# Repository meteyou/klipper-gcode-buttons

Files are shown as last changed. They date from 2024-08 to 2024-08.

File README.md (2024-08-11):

# Klipper Gcode-Buttons

The Klipper Gcode-Buttons offer a unique control and status display solution in 3D printers and automated systems.
Executing gcodes directly via hardware buttons and displaying the status visually significantly increases
user-friendliness. The CANBUS support as a USB-to-CAN adapter and the additional interfaces, such as SPI and I2C, offer
extra benefits and significantly expand the application possibilities.

To learn more about the Klipper Gcode-Buttons, check out the documentation:
[Klipper Gcode-Buttons Documentation](https://gcode-buttons.meteyou.wtf)

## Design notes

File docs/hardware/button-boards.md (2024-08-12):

# Button Boards

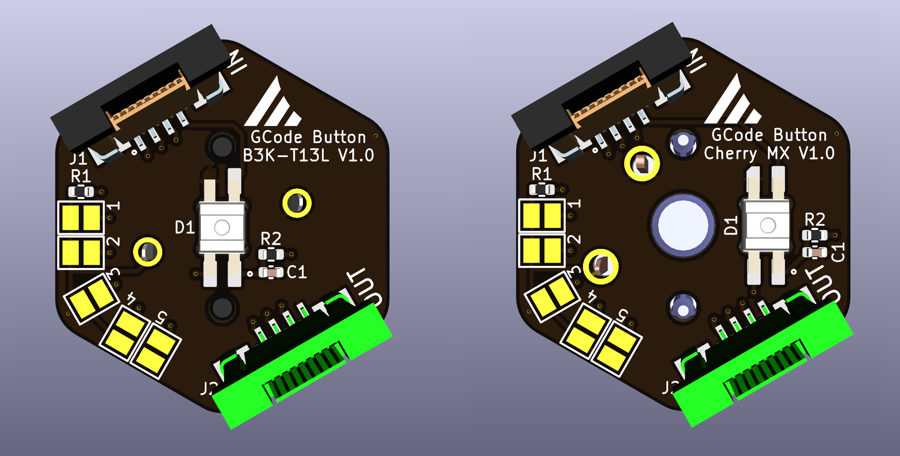
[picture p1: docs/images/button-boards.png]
Button Boards Rendering


The Button Boards are specially developed PCBs that enable intuitive and visually appealing control for Klipper-based 3D
printers. These small PCBs have two versions: one for **Cherry-MX** buttons and one for **Romer-G (B3K-T1RL)** buttons.
Both versions offer a high-quality, precise switching mechanism specially developed for demanding applications.

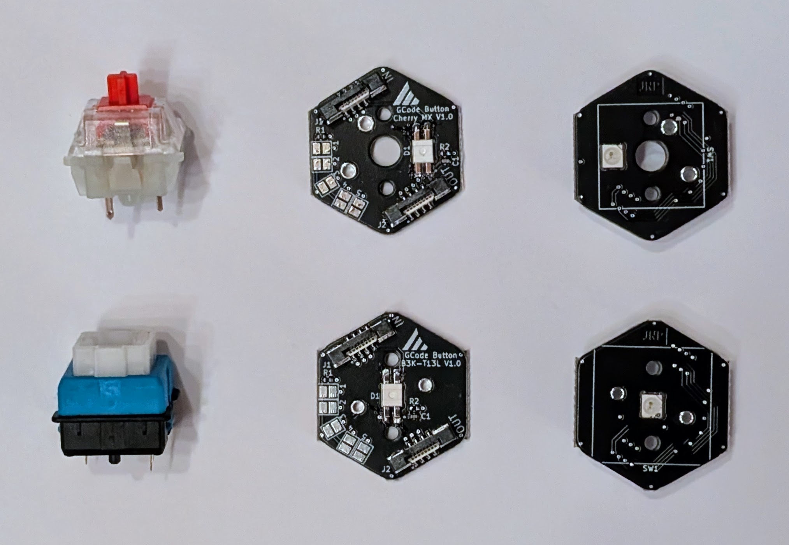
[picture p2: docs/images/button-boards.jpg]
Button Boards


Each button board is equipped with a NeoPixel, which illuminates the button from behind and serves as a status
indicator. This LED can be individually programmed to visualize the system's current status or specific functions.
This integrated lighting provides an aesthetic enhancement and clear visual feedback directly on the push-button.

Solder pads are placed on the PCBs to set the order of the buttons in the daisy chain. The button boards are connected
via FFC/FPC flat cables with 8 pins and a 0.5 mm pitch, which ensures simple and tidy cabling.

The Button Boards, therefore, offer an excellent combination of functionality, flexibility, and design, making them the
ideal addition to any Klipper-based control system. Whether you prefer Cherry-MX or Romer-G buttons, both versions
deliver precise and reliable performance, further enhanced by the integrated status lighting.

## Features
- 2 versions: Cherry-MX and Romer-G (B3K-T1RL)
- integrated NeoPixel LED for status indication
- daisy chain connection via FFC/FPC flat cables (8-pin, 0.5 mm pitch)
- solder pads for setting the button order

## Pinout
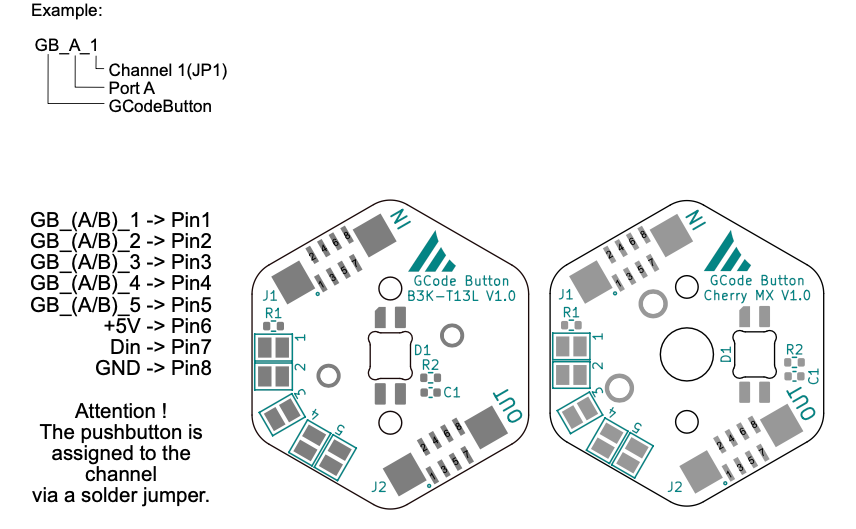
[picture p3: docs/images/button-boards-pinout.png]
Button Boards Pinout


## Downloads
- [Cherry-MX Button Board Schematic](https://github.com/meteyou/klipper-gcode-buttons/blob/main/hardware/GCode_Buttons_Cherry_MX/Schematic/GCode_Buttons_Cherry_MX.pdf){:target="_blank"}
- [Cherry-MX Button Board KiCad Project](https://github.com/meteyou/klipper-gcode-buttons/blob/main/hardware/GCode_Buttons_Cherry_MX/){:target="_blank"}
- [Cherry-MX Button Board CAD Model](https://github.com/meteyou/klipper-gcode-buttons/blob/main/hardware/GCode_Buttons_Cherry_MX/CAD/GCode_Buttons_Cherry_MX_PCB.step){:target="_blank"}
- [Romer-G Button Board Schematic](https://github.com/meteyou/klipper-gcode-buttons/blob/main/hardware/GCode_Buttons_B3K-T13L/Schematic/GCode_Buttons_B3K-T13L.pdf){:target="_blank"}
- [Romer-G Button Board KiCad Project](https://github.com/meteyou/klipper-gcode-buttons/tree/main/hardware/GCode_Buttons_B3K-T13L){:target="_blank"}
- [Romer-G Button Board CAD Model](https://github.com/meteyou/klipper-gcode-buttons/blob/main/hardware/GCode_Buttons_B3K-T13L/CAD/GCode_Buttons_B3K-T13L_PCB.step){:target="_blank"}

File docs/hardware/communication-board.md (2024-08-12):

# Communication Board
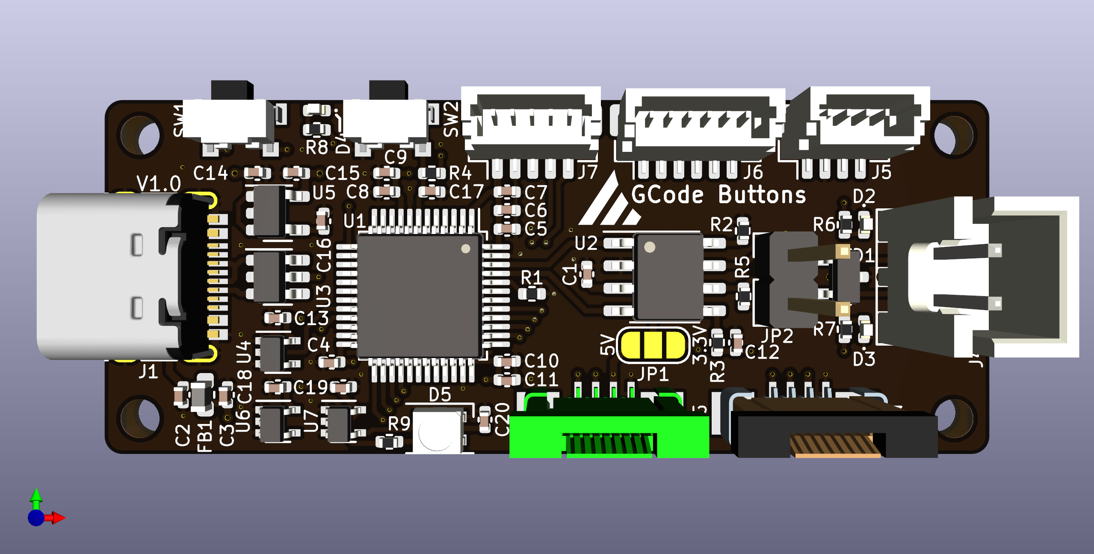
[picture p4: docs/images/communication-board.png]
Communication Board Rendering


The main communication board is a compact, versatile solution designed to optimize control and communication in 
Klipper-based systems. This small board can be connected to the Klipper host (SBC) via USB or CAN. The board can also be
used as a USB-to-CAN bridge with a USB connection, making it an ideal choice for integrating CAN toolhead boards into
Klipper.

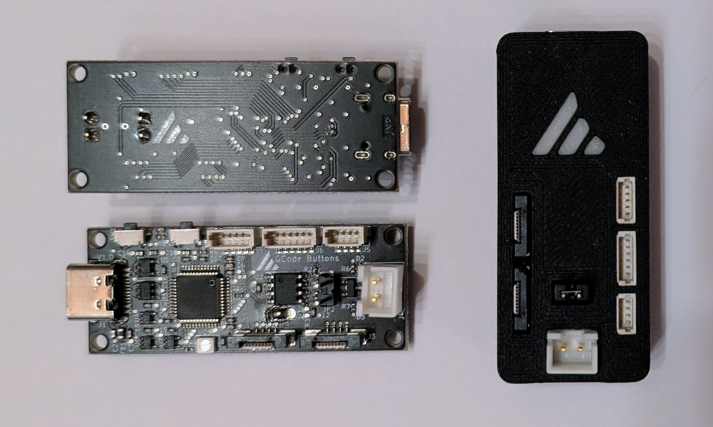
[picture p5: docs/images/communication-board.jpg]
Communication Board


The board allows the connection of up to 10 hardware buttons connected via flexible FFC/FPC flat cables (8-pin, 0.5 mm
pitch). The buttons are organized in two daisy chains, each supporting up to 5 buttons. This architecture ensures simple
and clean cabling that is also flexible and expandable.

At the heart of the board is a powerful STM32F072 MCU with native hardware support for CAN. This ensures reliable and
fast communication, especially in advanced Klipper 3D printers.

Therefore, this main communication board is a central component for advanced control and communication tasks in modern
Klipper systems and offers a wide range of applications thanks to its compact design and powerful features.

## Features
- 2x 5 buttons with NeoPixel LEDs (daisy chain via FFC/FPC flat cables 8-pin, 0.5 mm pitch)
- STM32F072 MCU
- SWD programming interface
- I2C and SPI interfaces
- USB interface with ESD protection
- CAN interface with ESD protection
- Katapult (Bootloader) support with status LED
- Reset button on the board
- BOOT0 button on the board (DFU mode)
- Supports 3.3V/4V CAN transceivers
- Onboard NeoPixel LED for status indication
- Level shifter for NeoPixel LEDs
- 5V power supply via USB

## Possible communications
- USB → CAN (USB-to-CAN Bridge)
- USB → SPI
- USB → I2C
- USB → Gcode-Buttons
- CAN → Gcode-Buttons
- CAN → SPI
- CAN → I2C

## Pinout
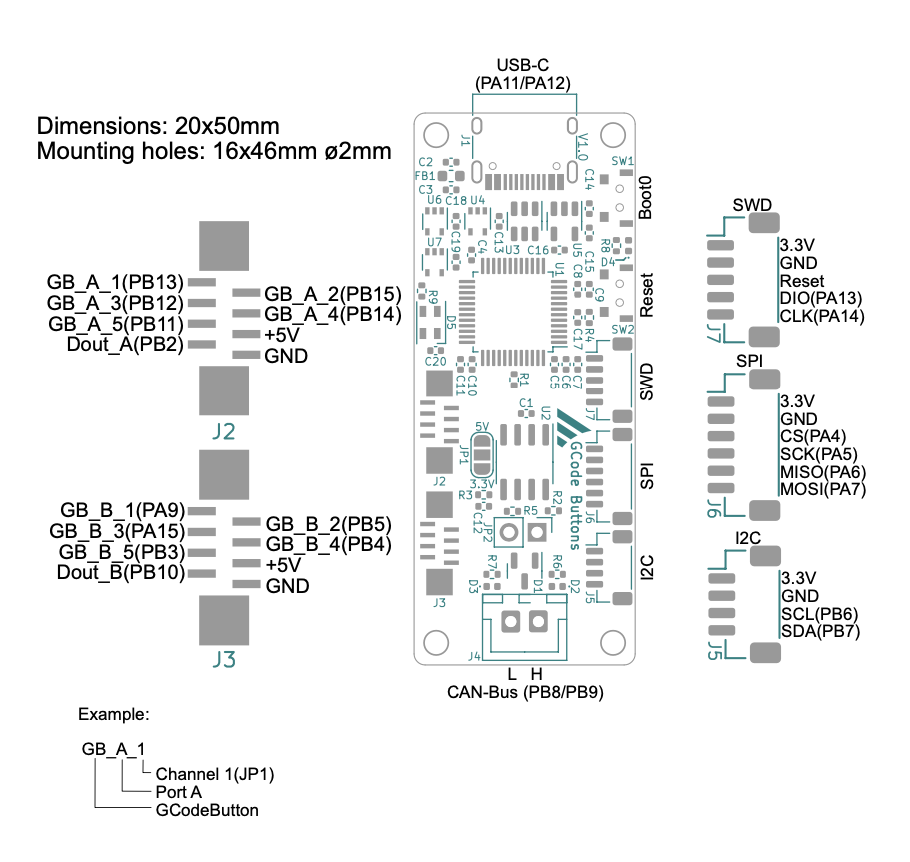
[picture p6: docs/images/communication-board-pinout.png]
Communication Board Pinout


## Downloads
- [Schematic](https://github.com/meteyou/klipper-gcode-buttons/blob/main/hardware/GCode_Buttons_MCU/Schematic/Schematic_GCode_Buttons_MCU.pdf){:target="_blank"}
- [KiCad Project](https://github.com/meteyou/klipper-gcode-buttons/tree/main/hardware/GCode_Buttons_MCU){:target="_blank"}
- [CAD Model](https://github.com/meteyou/klipper-gcode-buttons/blob/main/hardware/GCode_Buttons_MCU/CAD/GCode_Buttons_MCU_PCB.step){:target="_blank"}
- [Pinout](https://github.com/meteyou/klipper-gcode-buttons/blob/main/hardware/Documentation/GCode_Buttons_PCBs.pdf){:target="_blank"}
- [MCU Case STLs](https://github.com/meteyou/klipper-gcode-buttons/tree/main/STLs/MCU_Case){:target="_blank"}
- [MCU Case Fusion 360](https://github.com/meteyou/klipper-gcode-buttons/blob/main/CAD/GCode_Buttons_MCU_Case.f3d){:target="_blank"}
- [MCU Case STEP](https://github.com/meteyou/klipper-gcode-buttons/blob/main/CAD/GCode_Buttons_MCU_Case.step){:target="_blank"}

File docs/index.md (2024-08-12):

---
hide:
  - toc
---

# Klipper Gcode-Buttons

The Klipper Gcode-Buttons offer an innovative control option specially developed to improve operation and status display
in 3D printing and automation systems. This solution supports ten hardware buttons, each equipped with a NeoPixel LED.
These buttons allow execution of gcodes directly while providing visual feedback on the current status via the
integrated NeoPixel LEDs.

## Features from the Klipper Gcode-Buttons

- **Hardware buttons:** Klipper Gcode-Buttons allow you to use up to 10 physical buttons to execute gcodes directly.
This provides an intuitive and fast way to execute commands without using a touchscreen, PC, or smartphone on your 3D
printer.

- **NeoPixel status indicators:** Each button is equipped with a NeoPixel LED that can be individually programmed to
display the status of the respective function or system. This means you always have clear visual feedback on the current
status.

- **Simple daisy-chain connection:** The hardware buttons and NeoPixel LEDs are connected via a daisy chain, which
enables uncomplicated cabling and expansion. This allows you to adapt the system to your needs flexibly.

- **CANBUS support:** The board can also be used as a **USB-to-CAN** adapter, making it a versatile solution for using
toolhead boards in Klipper 3D printers. This enables stable and fast communication between the SBC/host and the toolhead
boards via CANBUS.

- **Additional interfaces:** Besides the core functionality, the board also offers support for interfaces such as SPI
and I2C, which provides extra flexibility for special applications.

- **Open-source hardware and software:** The Klipper Gcode-Buttons are based on open-source hardware and software. This
allows you to adapt the system to your needs and expand it as required.

The Klipper Gcode-Buttons offer a unique control and status display solution in 3D printers and automated systems.
Executing gcodes directly via hardware buttons and displaying the status visually significantly increases
user-friendliness. The CANBUS support as a USB-to-CAN adapter and the additional interfaces, such as SPI and I2C, offer
extra benefits and significantly expand the application possibilities.

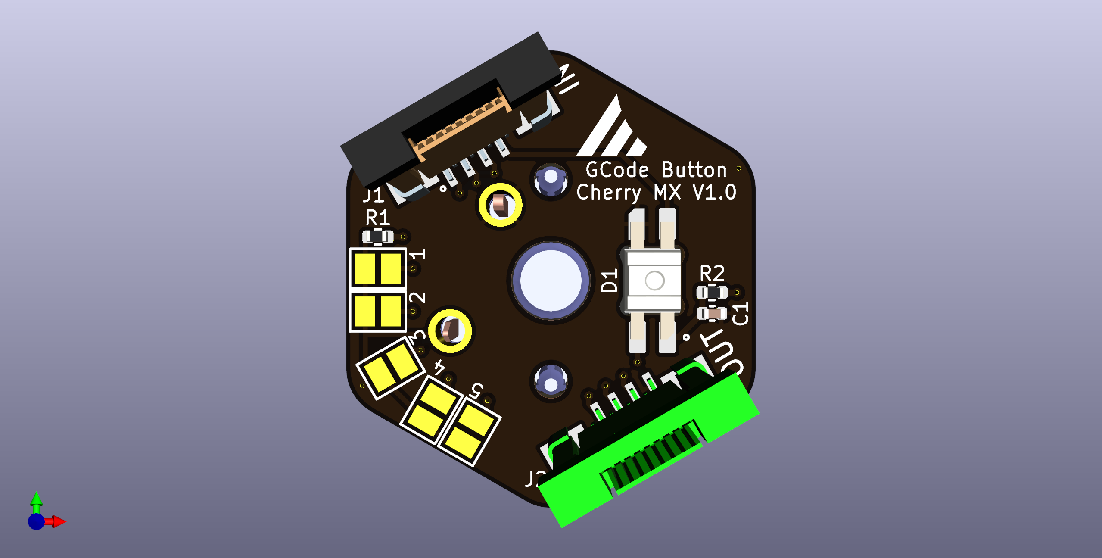
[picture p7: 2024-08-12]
hardware/GCode_Buttons_Cherry_MX/GCode_Buttons_Cherry_MX.png

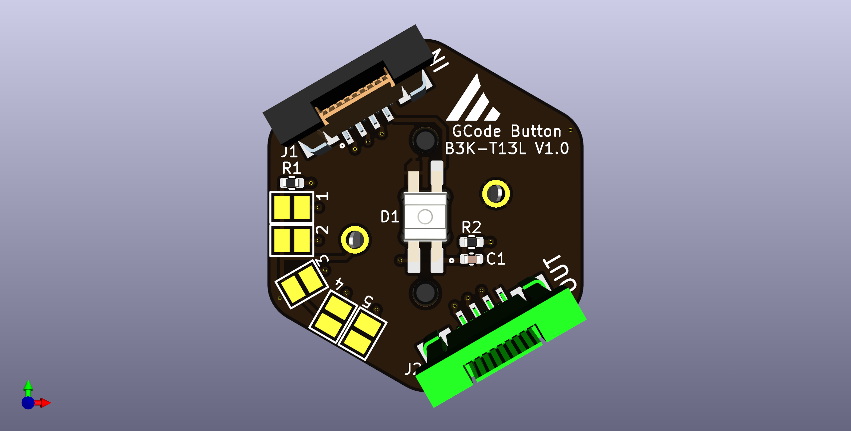
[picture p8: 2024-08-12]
hardware/GCode_Buttons_B3K-T13L/GCode_Buttons_B3K-T13L.png

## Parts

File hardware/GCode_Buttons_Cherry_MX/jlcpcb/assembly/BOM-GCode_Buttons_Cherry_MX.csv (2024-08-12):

Comment | Designator | Footprint | LCSC
10k | R1 | R_0402_1005Metric | C144807
100R | R2 | R_0402_1005Metric | C25076
Conn_01x08 | J1,J2 | JUSHUO AFC11-S08ICC-00 | C262301
100n | C1 | C_0402_1005Metric | C60474
SK6812mini-e | D1 | SK6812MINI-E | C524051

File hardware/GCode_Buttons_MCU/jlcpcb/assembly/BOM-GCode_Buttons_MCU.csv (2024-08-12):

Comment | Designator | Footprint | LCSC
22n | C16 | C_0402_1005Metric | C107026
USB_C_Receptacle_USB2.0 | J1 | USB_C_Receptacle_HRO_TYPE-C-31-M-12 | C136423
1k | R6,R7,R8 | R_0402_1005Metric | C144789
10k | R1,R4 | R_0402_1005Metric | C144807
I2C | J5 | JST_SH_BM04B-SRSS-TB_1x04-1MP_P1.00mm_Vertical | C145961
600Z | FB1 | L_0603_1608Metric | C19330
74LVC1G17GW | U4,U6,U7 | SOT-353_SC-70-5 | C202202
100R | R9 | R_0402_1005Metric | C25076
120R | R5 | R_0402_1005Metric | C25079
GCode_Buttons_A | J2,J3 | JUSHUO AFC11-S08ICC-00 | C262301
B2B-XH-A-GU | J4 | JST_XH_B2B-XH-A_1x02_P2.50mm_Vertical | C265283
NUP2105LT1G | D1 | SOT-23 | C2976509
SWD | J7 | C145962 | C145962
SPI | J6 | C145963 | C145963
SW_Push | SW1,SW2 | SW_SPST_1TS003B-1400-3500A-CT | C319392
10nF | C8 | C_0402_1005Metric | C327025
4u7 | C11,C6 | C_0402_1005Metric | C368809
TLV74333PDBVR | U5 | SOT-23-5 | C408972
2u2 | C15 | C_0402_1005Metric | C415540
MHT136UBCT | D3 | LED_0402_1005Metric | C401112
MHT136CGCT | D2 | LED_0402_1005Metric | C401111
CAN | JP2 | PinHeader_1x02_P2.54mm_Vertical | C492401
1uF/10V | C14,C2,C3,C9 | C_0402_1005Metric | C528974
100nF | C1,C10,C12,C13,C17,C18,C19,C20,C4,C5,C7 | C_0402_1005Metric | C60474
red | D4 | LED_0402_1005Metric | C71911
MCP2551-I-SN | U2 | SOIC-8_3.9x4.9mm_P1.27mm | C7376
USBLC6-2SC6 | U3 | SOT-23-6 | C7519
SK6805 | D5 | LED_SK6805_PLCC4_2.4x2.7mm_P1.3mm | C784561
STM32F072C8T6 | U1 | LQFP-48_7x7mm_P0.5mm | C80488

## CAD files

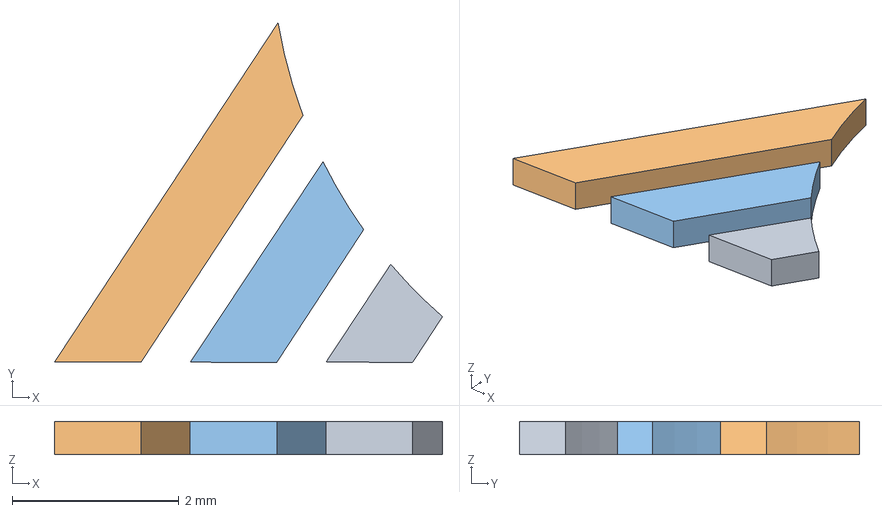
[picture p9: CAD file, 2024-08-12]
CAD/Mainsail_Logo.step
4.66 x 4.08 x 0.4 mm
Komponente1
Komponente3
Komponente2

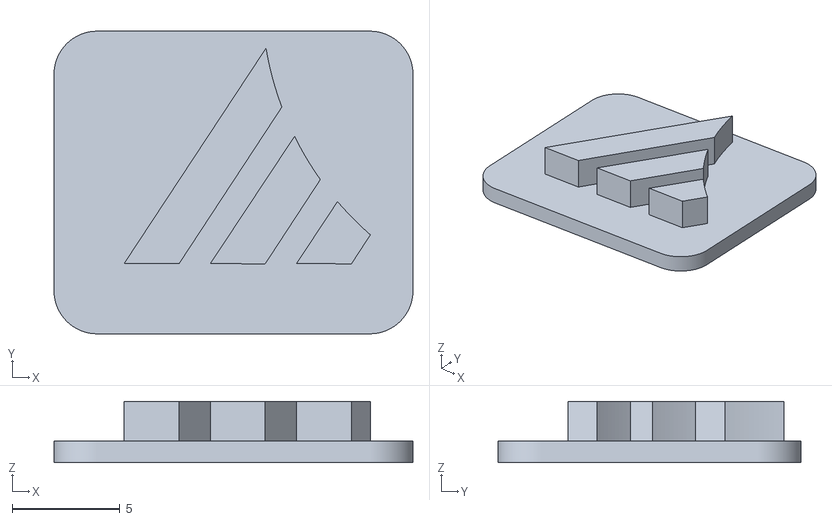
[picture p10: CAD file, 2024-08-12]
STLs/MCU_Case/MCU_led_diffuser_Mainsail.stl
16.6 x 14.0 x 2.85

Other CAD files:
CAD/GCode_Buttons_MCU_Case.f3d

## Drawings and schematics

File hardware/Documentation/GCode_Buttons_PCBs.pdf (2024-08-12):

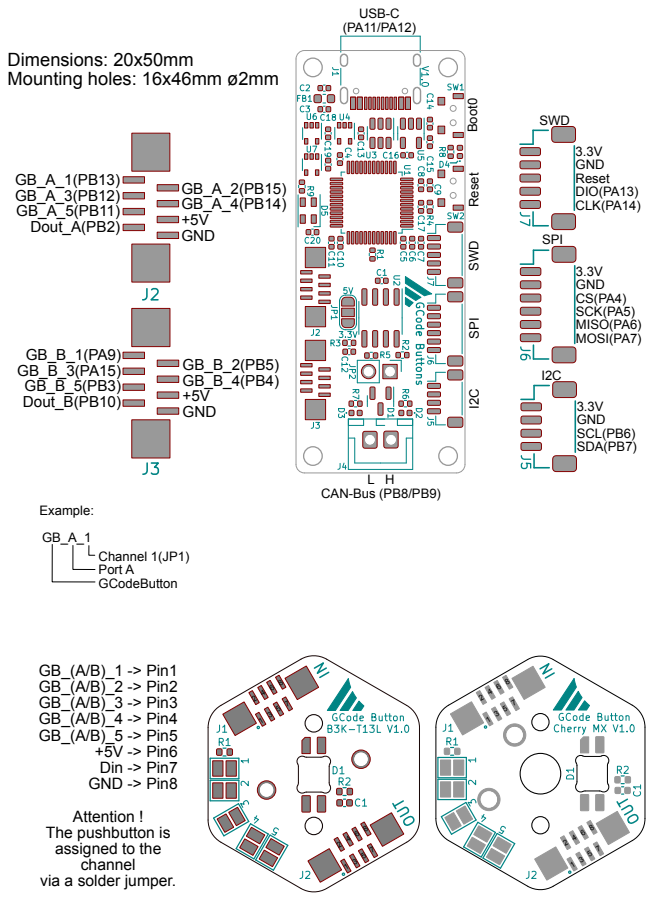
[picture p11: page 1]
GB_A_1(PB13) GB_A_3(PB12) GB_A_5(PB11) Dout_A(PB2); GB_A_2(PB15) GB_A_4(PB14) +5V GND; GB_B_1(PA9) GB_B_3(PA15) GB_B_5(PB3) Dout_B(PB10); GB_B_2(PB5) GB_B_4(PB4) +5V GND; 3.3V GND Reset DIO(PA13) CLK(PA14); 3.3V GND CS(PA4) SCK(PA5) MISO(PA6) MOSI(PA7); 3.3V GND SCL(PB6) SDA(PB7); SWD; SPI; SPI I2C Reset Boot0; USB-C (PA11/PA12); L H CAN-Bus (PB8/PB9); Dimensions: 20x50mm Mounting holes: 16x46mm ø2mm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

Attention !
The pushbutton is
assigned to the
channel
via a solder jumper.

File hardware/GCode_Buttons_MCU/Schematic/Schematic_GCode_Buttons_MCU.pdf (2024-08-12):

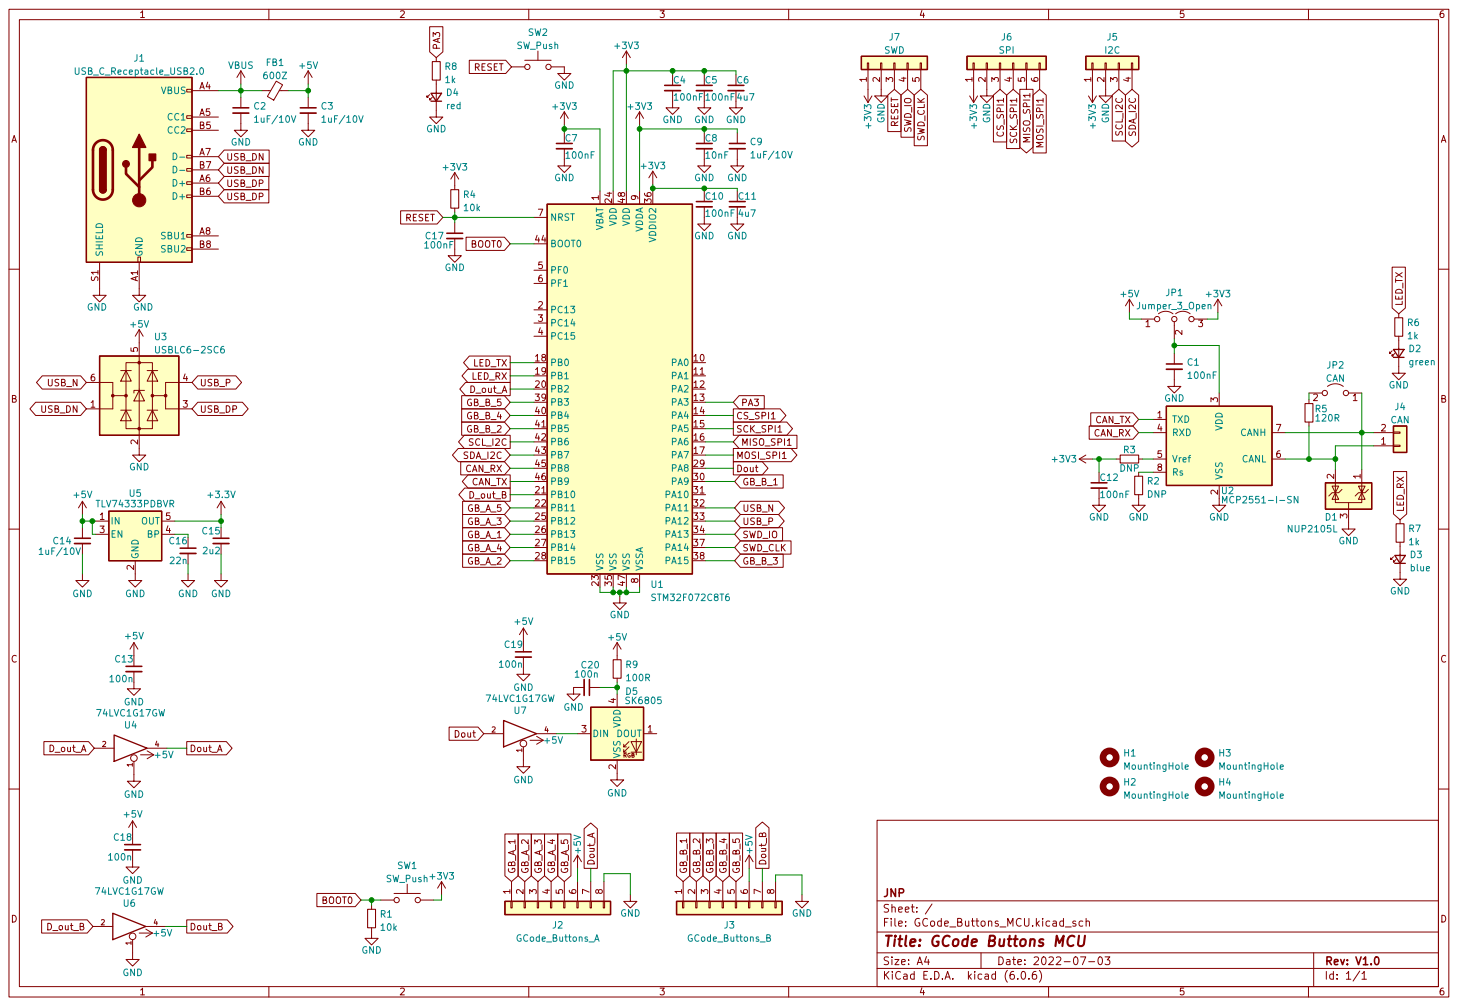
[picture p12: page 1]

1 PA0 10 PA1 11 PA2 12 PA3 13 PA4 14 PA5 15 PA6 16 PA7 17 PB0 18 PB1 19 PC13 2 PB2 20 PB10 21 PB11 22 VSS 23 VDD 24 PB12 25 PB13 26 PB14 27 PB15 28 PA8 29 PC14 3 PA9 30 PA10 31 PA11 32 PA12 33 PA13 34 VSS 35 VDDIO2 36 PA14 37 PA15 38 PB3 39 PC15 4 PB4 40 PB5 41 PB6 42 PB7 43 BOOT0 44 PB8 45 PB9 46 VSS 47 VDD 48 PF0 5 PF1 6 NRST 7 VSSA

3 RXD 4 Vref 5 CANL 6 CANH 7 Rs 8 U2MCP2551-I-SN GND

Id: 1/1 Title: GCode Buttons MCU

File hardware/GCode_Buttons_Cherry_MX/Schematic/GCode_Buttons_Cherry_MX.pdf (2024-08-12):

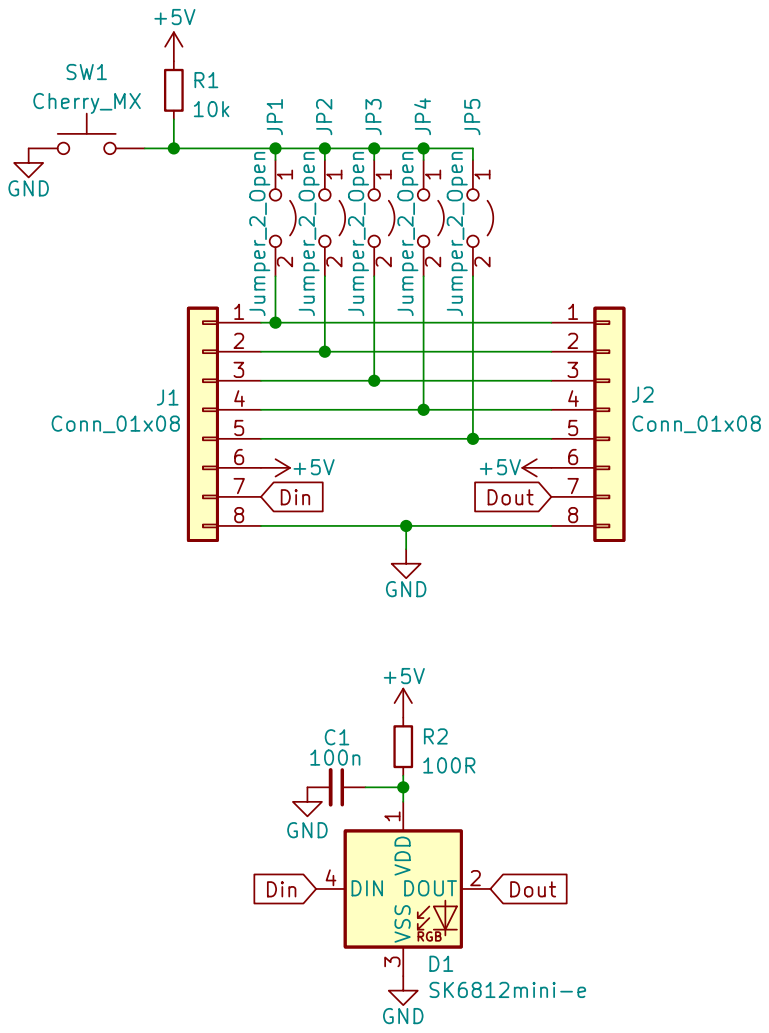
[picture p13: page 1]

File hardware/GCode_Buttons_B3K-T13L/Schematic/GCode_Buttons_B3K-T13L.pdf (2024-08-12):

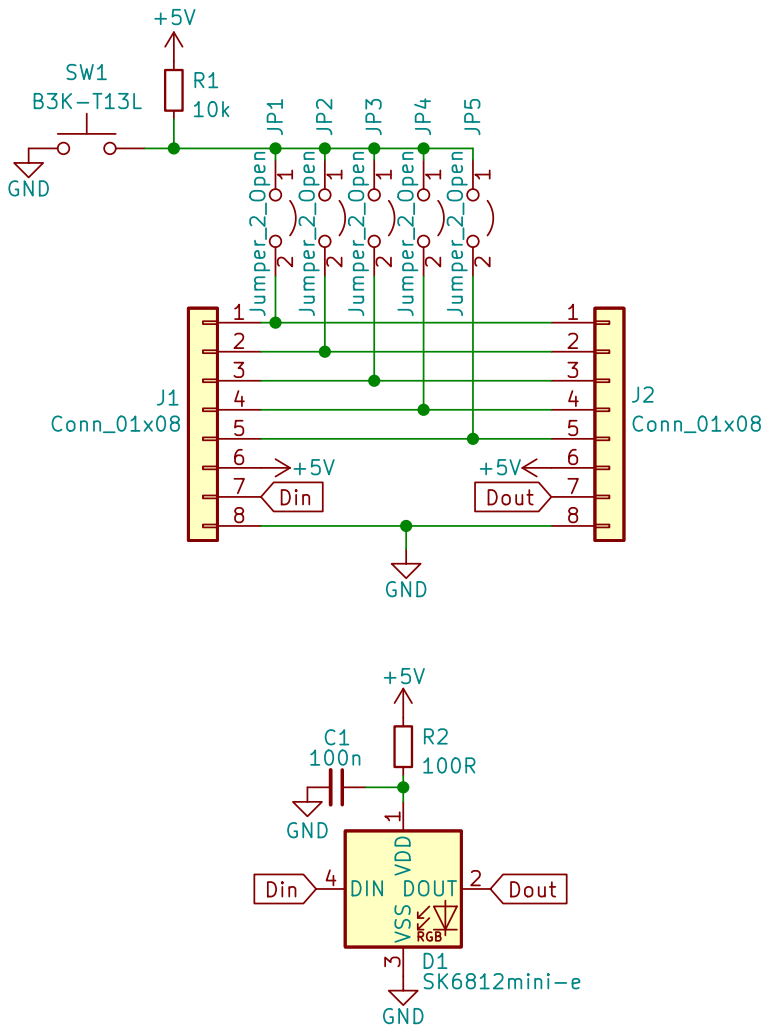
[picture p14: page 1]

3 DIN 4 D1SK6812mini-e Din Dout Din Dout

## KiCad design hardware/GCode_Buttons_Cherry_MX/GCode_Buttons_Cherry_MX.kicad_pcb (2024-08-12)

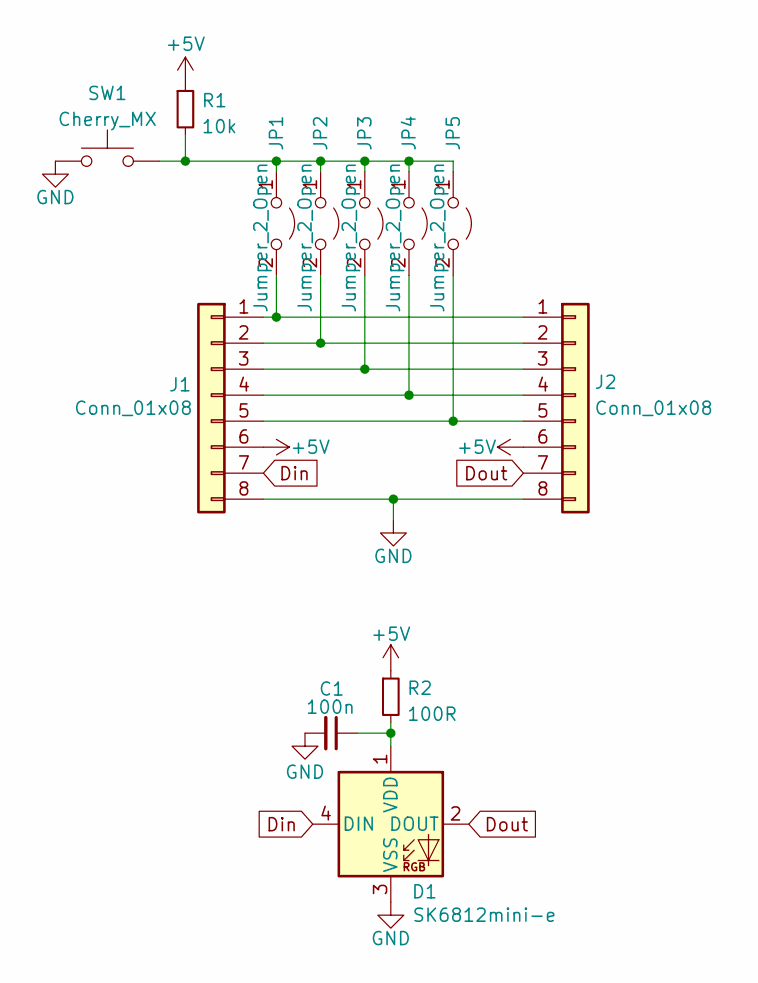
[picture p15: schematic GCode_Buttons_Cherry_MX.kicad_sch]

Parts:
C1: 100n; C_0402_1005Metric; LCSC C60474
D1: SK6812mini-e; SK6812MINI-E; LCSC C784561
J1, J2: Conn_01x08; JUSHUO AFC11-S08ICC-00; LCSC C262301
JP1, JP2, JP3, JP4, JP5: Jumper_2_Open; SolderJumper-2_P1.3mm_Open_Pad1.0x1.5mm
R1: 10k; R_0402_1005Metric; LCSC C144807
R2: 100R; R_0402_1005Metric; LCSC C25076
SW1: Cherry_MX; SW_Cherry_MX_1.00u_PCB

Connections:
+5V: J1.6, J2.6, R1.1, R2.1
Din: D1.4 (DIN), J1.7
Dout: D1.2 (DOUT), J2.7
GND: C1.2, D1.3 (VSS), J1.8, J2.8, SW1.2
unnamed: C1.1, D1.1 (VDD), R2.2
unnamed: J1.1, J2.1, JP1.2 (B)
unnamed: J1.2, J2.2, JP2.2 (B)
unnamed: J1.3, J2.3, JP3.2 (B)
unnamed: J1.4, J2.4, JP4.2 (B)
unnamed: J1.5, J2.5, JP5.2 (B)
unnamed: JP1.1 (A), JP2.1 (A), JP3.1 (A), JP4.1 (A), JP5.1 (A), R1.2, SW1.1

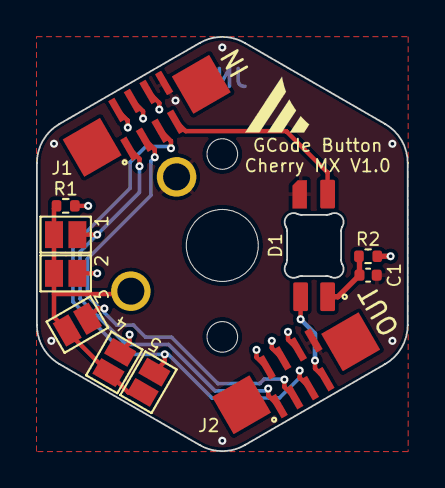
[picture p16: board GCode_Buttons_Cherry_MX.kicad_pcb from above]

Board: 4 copper layers, 20.6 x 23.0 mm, 12 parts (1 on the bottom side), 11 nets.

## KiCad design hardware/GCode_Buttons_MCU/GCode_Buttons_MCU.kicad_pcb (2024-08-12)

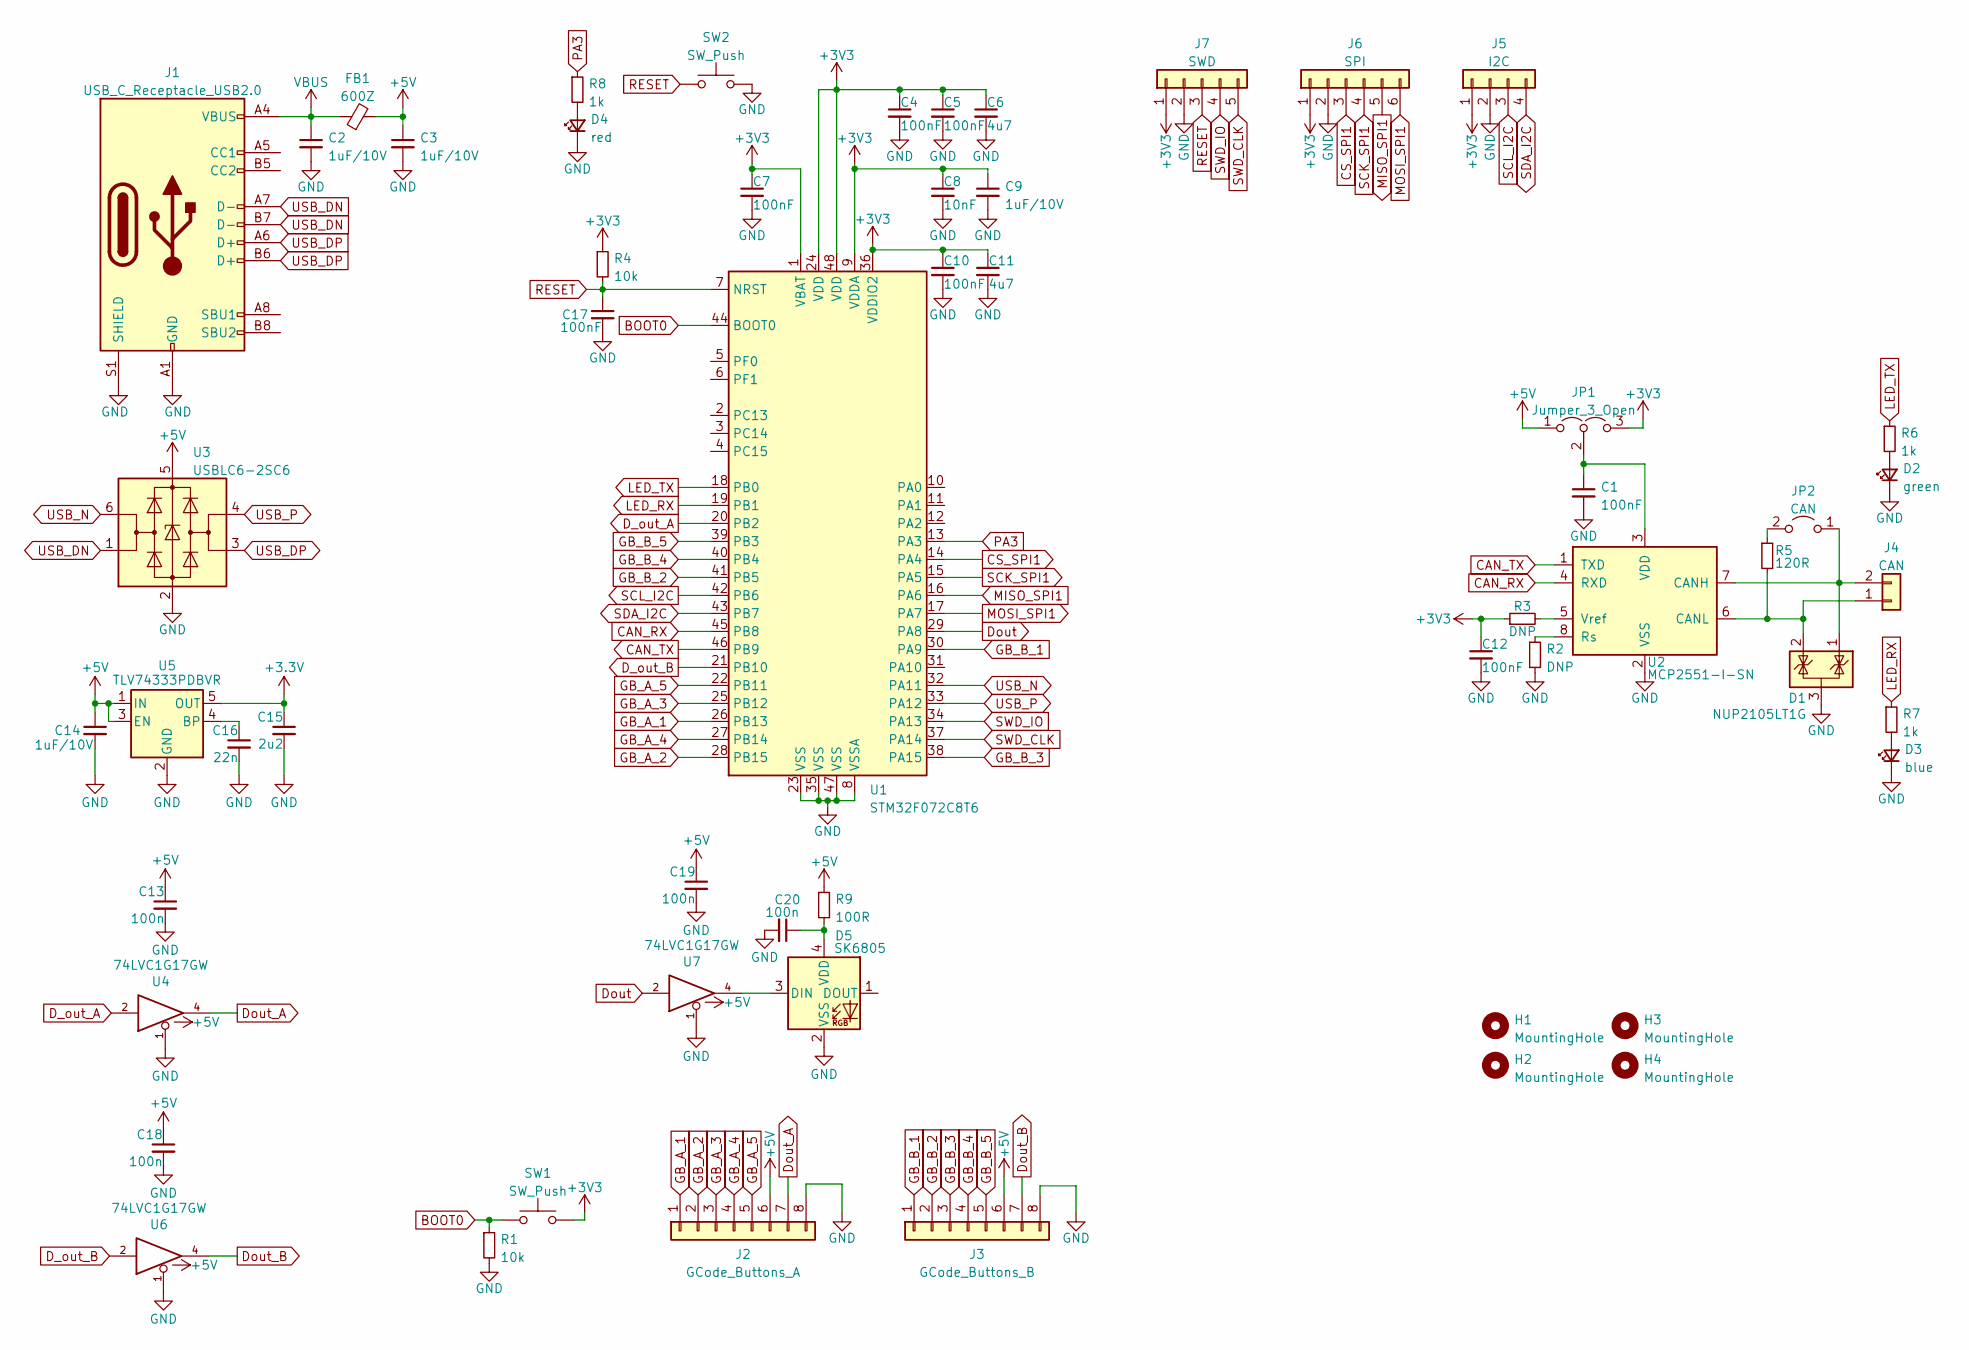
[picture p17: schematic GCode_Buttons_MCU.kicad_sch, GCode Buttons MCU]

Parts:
C1, C4, C5, C7, C10, C12, C17: 100nF; C_0402_1005Metric; LCSC C60474
C2, C3, C9, C14: 1uF/10V; C_0402_1005Metric; LCSC C528974
C6, C11: 4u7; C_0402_1005Metric; LCSC C368809
C8: 10nF; C_0402_1005Metric; LCSC C327025
C13, C18, C19, C20: 100n; C_0402_1005Metric; LCSC C60474
C15: 2u2; C_0402_1005Metric; LCSC C415540
C16: 22n; C_0402_1005Metric; LCSC C107026
D1: NUP2105LT1G; SOT-23; LCSC C2976509
D2: green; LED_0402_1005Metric; LCSC C401111
D3: blue; LED_0402_1005Metric; LCSC C401112
D4: red; LED_0402_1005Metric; LCSC C71911
D5: SK6805; LED_SK6805_PLCC4_2.4x2.7mm_P1.3mm; LCSC C784561
FB1: 600Z; L_0603_1608Metric; LCSC C19330
H1, H2, H3, H4: MountingHole; MountingHole_2.2mm_M2_DIN965
J1: USB_C_Receptacle_USB2.0; USB_C_Receptacle_HRO_TYPE-C-31-M-12; LCSC C136423
J2: GCode_Buttons_A; JUSHUO AFC11-S08ICC-00; LCSC C262301
J3: GCode_Buttons_B; JUSHUO AFC11-S08ICC-00; LCSC C262301
J4: CAN; JST_XH_B2B-XH-A_1x02_P2.50mm_Vertical; LCSC C265283
J5: I2C; JST_SH_BM04B-SRSS-TB_1x04-1MP_P1.00mm_Vertical; LCSC C145961
J6: SPI; JST_SH_BM06B-SRSS-TB_1x06-1MP_P1.00mm_Vertical; LCSC C145963
J7: SWD; JST_SH_BM05B-SRSS-TB_1x05-1MP_P1.00mm_Vertical; LCSC C3041143
JP1: Jumper_3_Open; SolderJumper-3_P1.3mm_Open_RoundedPad1.0x1.5mm_NumberLabels
JP2: CAN; PinHeader_1x02_P2.54mm_Vertical; LCSC C492401
R1, R4: 10k; R_0402_1005Metric; LCSC C144807
R2, R3: DNP; R_0402_1005Metric
R5: 120R; R_0402_1005Metric; LCSC C25079
R6, R7, R8: 1k; R_0402_1005Metric; LCSC C144789
R9: 100R; R_0402_1005Metric; LCSC C25076
SW1, SW2: SW_Push; SW_SPST_1TS003B-1400-3500A-CT; LCSC C319392
U1: STM32F072C8T6; LQFP-48_7x7mm_P0.5mm; LCSC C80488
U2: MCP2551-I-SN; SOIC-8_3.9x4.9mm_P1.27mm; LCSC C7376
U3: USBLC6-2SC6; SOT-23-6; LCSC C7519
U4, U6, U7: 74LVC1G17GW; SOT-353_SC-70-5; LCSC C202202
U5: TLV74333PDBVR; SOT-23-5; LCSC C408972

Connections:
+5V: C3.1, C13.1, C14.1, C18.1, C19.1, FB1.2, J2.6, J3.6, JP1.1 (A), R9.1, U3.5 (VBUS), U4.5 (VCC), U5.1 (IN), U5.3 (EN), U6.5 (VCC), U7.5 (VCC)
BOOT0: R1.1, SW1.1, U1.44 (BOOT0)
CAN_RX: U1.45 (PB8), U2.4 (RXD)
CAN_TX: U1.46 (PB9), U2.1 (TXD)
CS_SPI1: J6.3, U1.14 (PA4)
D_out_A: U1.20 (PB2), U4.2
D_out_B: U1.21 (PB10), U6.2
Dout: U1.29 (PA8), U7.2
Dout_A: J2.7, U4.4
Dout_B: J3.7, U6.4
GB_A_1: J2.1, U1.26 (PB13)
GB_A_2: J2.2, U1.28 (PB15)
GB_A_3: J2.3, U1.25 (PB12)
GB_A_4: J2.4, U1.27 (PB14)
GB_A_5: J2.5, U1.22 (PB11)
GB_B_1: J3.1, U1.30 (PA9)
GB_B_2: J3.2, U1.41 (PB5)
GB_B_3: J3.3, U1.38 (PA15)
GB_B_4: J3.4, U1.40 (PB4)
GB_B_5: J3.5, U1.39 (PB3)
GND: C1.2, C2.2, C3.2, C4.2, C5.2, C6.2, C7.2, C8.2, C9.2, C10.2, C11.2, C12.2, C13.2, C14.2, C15.2, C16.2, C17.2, C18.2, C19.2, C20.2, D1.3 (A), D2.1 (K), D3.1 (K), D4.1 (K), D5.2 (VSS), J1.A1 (GND), J1.A12 (GND), J1.B1 (GND), J1.B12 (GND), J1.S1 (SHIELD), J2.8, J3.8, J5.2, J6.2, J7.2, R1.2, R2.2, SW2.1, U1.8 (VSSA), U1.23 (VSS), U1.35 (VSS), U1.47 (VSS), U2.2 (VSS), U3.2 (GND), U4.1, U4.3 (GND), U5.2 (GND), U6.1, U6.3 (GND), U7.1, U7.3 (GND)
LED_RX: R7.1, U1.19 (PB1)
LED_TX: R6.1, U1.18 (PB0)
MISO_SPI1: J6.5, U1.16 (PA6)
MOSI_SPI1: J6.6, U1.17 (PA7)
unnamed: C1.1, JP1.2 (C), U2.3 (VDD)
unnamed: C16.1, U5.4 (BP)
unnamed: C20.1, D5.4 (VDD), R9.2
unnamed: D1.1 (K), J4.2, JP2.1 (A), U2.7 (CANH)
unnamed: D1.2 (K), J4.1, R5.2, U2.6 (CANL)
unnamed: D2.2 (A), R6.2
unnamed: D3.2 (A), R7.2
unnamed: D4.2 (A), R8.2
unnamed: D5.3 (DIN), U7.4
unnamed: JP2.2 (B), R5.1
unnamed: R2.1, U2.8 (Rs)
unnamed: R3.2, U2.5 (Vref)
PA3: R8.1, U1.13 (PA3)
RESET: C17.1, J7.3, R4.2, SW2.2, U1.7 (NRST)
SCK_SPI1: J6.4, U1.15 (PA5)
SCL_I2C: J5.3, U1.42 (PB6)
SDA_I2C: J5.4, U1.43 (PB7)
SWD_CLK: J7.5, U1.37 (PA14)
SWD_IO: J7.4, U1.34 (PA13)
USB_DN: J1.A7 (D-), J1.B7 (D-), U3.1 (I/O1)
USB_DP: J1.A6 (D+), J1.B6 (D+), U3.3 (I/O2)
USB_N: U1.32 (PA11), U3.6 (I/O1)
USB_P: U1.33 (PA12), U3.4 (I/O2)
VBUS: C2.1, FB1.1, J1.A4 (VBUS), J1.A9 (VBUS), J1.B4 (VBUS), J1.B9 (VBUS)

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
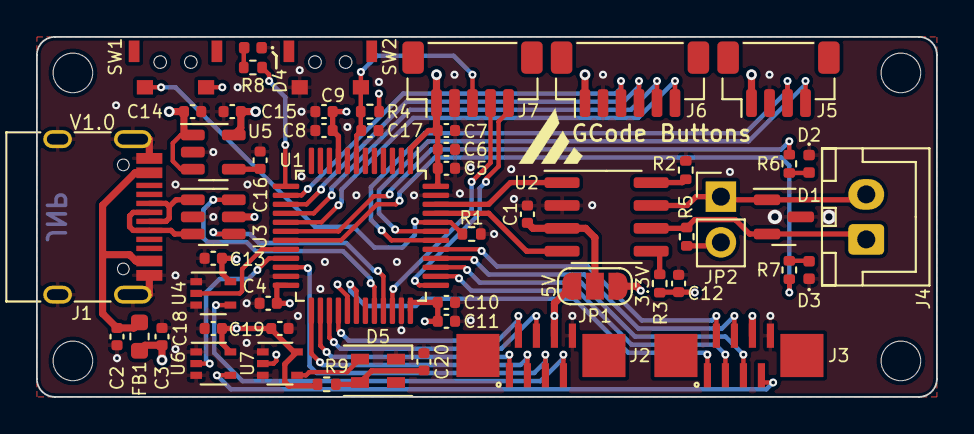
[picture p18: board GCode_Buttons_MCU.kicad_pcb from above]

Board: 4 copper layers, 50.0 x 20.0 mm, 57 parts (0 on the bottom side), 50 nets.

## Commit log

2024-08-11 docs: init index.md description from the gcode-buttons
2024-08-12 feat: upload Communication Board files
    [BOM-GCode_Buttons_MCU.csv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]
2024-08-12 feat: upload CAD files for MCU case
    [GCode_Buttons_MCU_Case.f3d, Mainsail_Logo.step]
2024-08-12 feat: upload STLs for MCU case
    [MCU_led_diffuser_Mainsail.stl]
2024-08-12 feat: upload pinout for Communication Board
2024-08-12 docs: add the communication board page + images
2024-08-12 feat: upload Romer-G hardware files
    [BOM-GCode_Buttons_B3K-T13L.csv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]
2024-08-12 feat: upload Cherry-MX hardware files
    [BOM-GCode_Buttons_Cherry_MX.csv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]
2024-08-12 docs: add page for the button boards
